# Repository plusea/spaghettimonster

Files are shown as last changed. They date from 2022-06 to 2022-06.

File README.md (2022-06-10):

# spaghettimonster

The spaghettimonster is a tool we developed for playing with wearable technology first, before making it yourself. It is basically a breakout board for an ESP32 Dev Module with six audio sockets connected to pins that have an Analog to Digital Converter (ADC). This allows one to then use audio cables to make electrical connections between the i/o pins of the ESP and textile/wearable sensors mounted around the body or in/on puppets or objects. Spaghettimonster babies are little breakout boards for audio sockets so that one can make connections with conductive thread from the socket to the textile sensor.

### CODE
* [Clock Divider's Spaghetti Monster Firmware](https://github.com/clockdiv/Spaghettimonster)

### LINKS
* [spaghettimonster intro](https://www.kobakant.at/DIY/?p=9137)
* [photos](https://www.flickr.com/photos/plusea/albums/72157719958295195)
* workshops that tested the spaghettimonster v1:
** [sensitive puppetes](https://www.flickr.com/photos/plusea/albums/72157713930789442)
** [communicating bodies]()



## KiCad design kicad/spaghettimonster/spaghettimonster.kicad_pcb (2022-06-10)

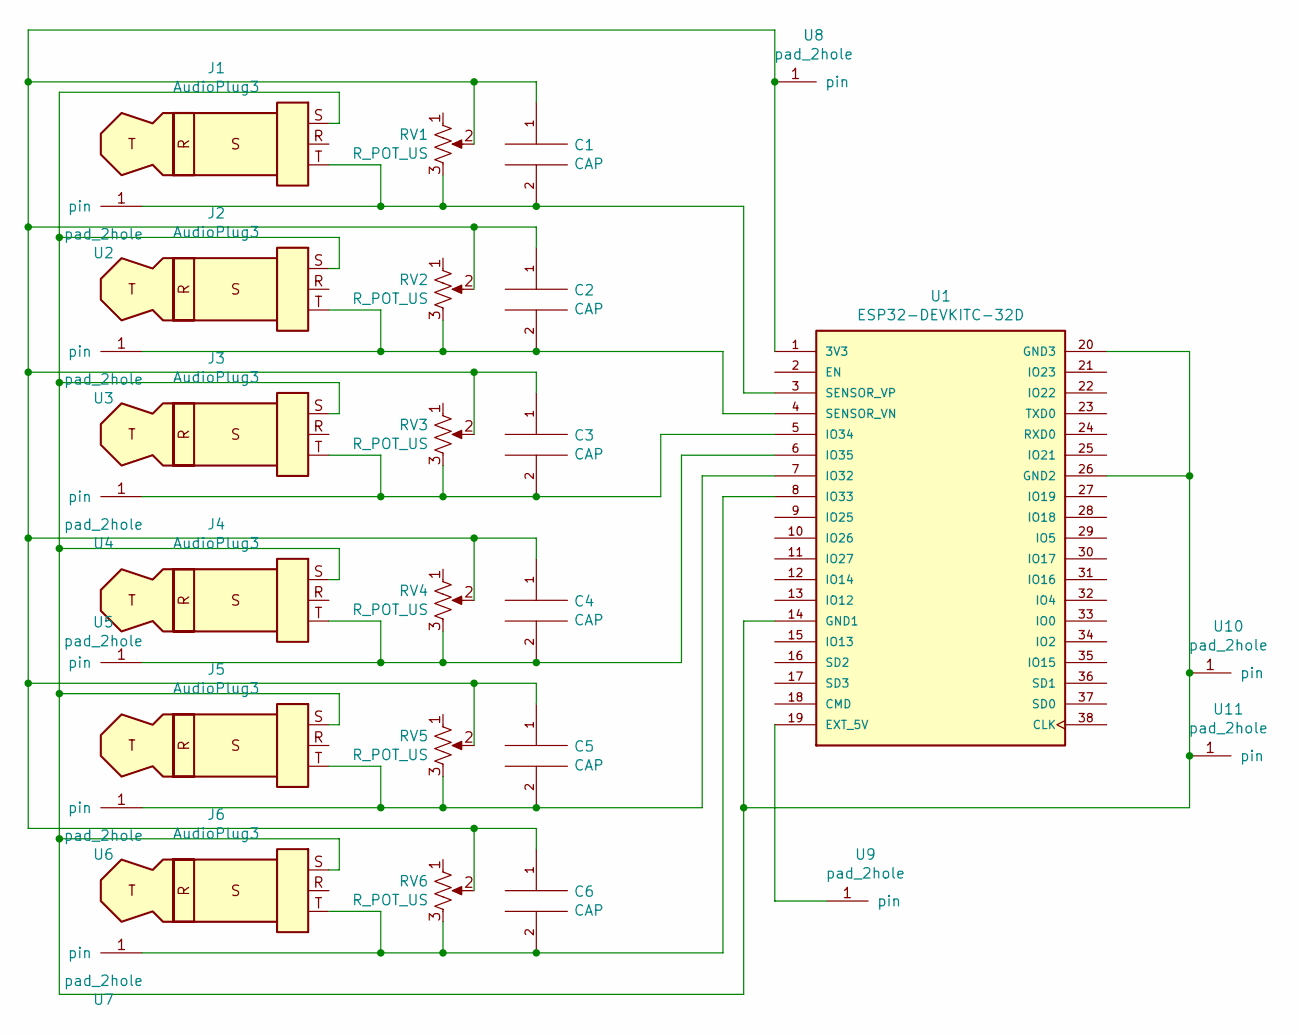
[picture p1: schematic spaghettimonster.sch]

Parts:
C1, C2, C3, C4, C5, C6: CAP; CP_Radial_D4.0mm_P2.00mm
J1, J2, J3, J4, J5, J6: AudioPlug3; Jack_3.5mm_Lumberg_1503_07_Horizontal
RV1, RV2, RV3, RV4, RV5, RV6: R_POT_US; Potentiometer_Trimmer_Piher_PT-6v_Horizontal
U1: ESP32-DEVKITC-32D; MODULE_ESP32-DEVKITC-32D; PARTREV 4
U2, U3, U4, U5, U6, U7, U8, U9, U10, U11: pad_2hole; pad_clip-edge-3mm

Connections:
unnamed: C1.1, C2.1, C3.1, C4.1, C5.1, C6.1, RV1.2, RV2.2, RV3.2, RV4.2, RV5.2, RV6.2, U1.1 (3V3), U8.1
unnamed: C1.2, J1.T, RV1.3, U1.3 (SENSOR_VP), U2.1
unnamed: C2.2, J2.T, RV2.3, U1.4 (SENSOR_VN), U3.1
unnamed: C3.2, J3.T, RV3.3, U1.5 (IO34), U4.1
unnamed: C4.2, J4.T, RV4.3, U1.6 (IO35), U5.1
unnamed: C5.2, J5.T, RV5.3, U1.7 (IO32), U6.1
unnamed: C6.2, J6.T, RV6.3, U1.8 (IO33), U7.1
unnamed: J1.S, J2.S, J3.S, J4.S, J5.S, J6.S, U1.14 (GND1), U1.20 (GND3), U1.26 (GND2), U10.1, U11.1
unnamed: U1.19 (EXT_5V), U9.1

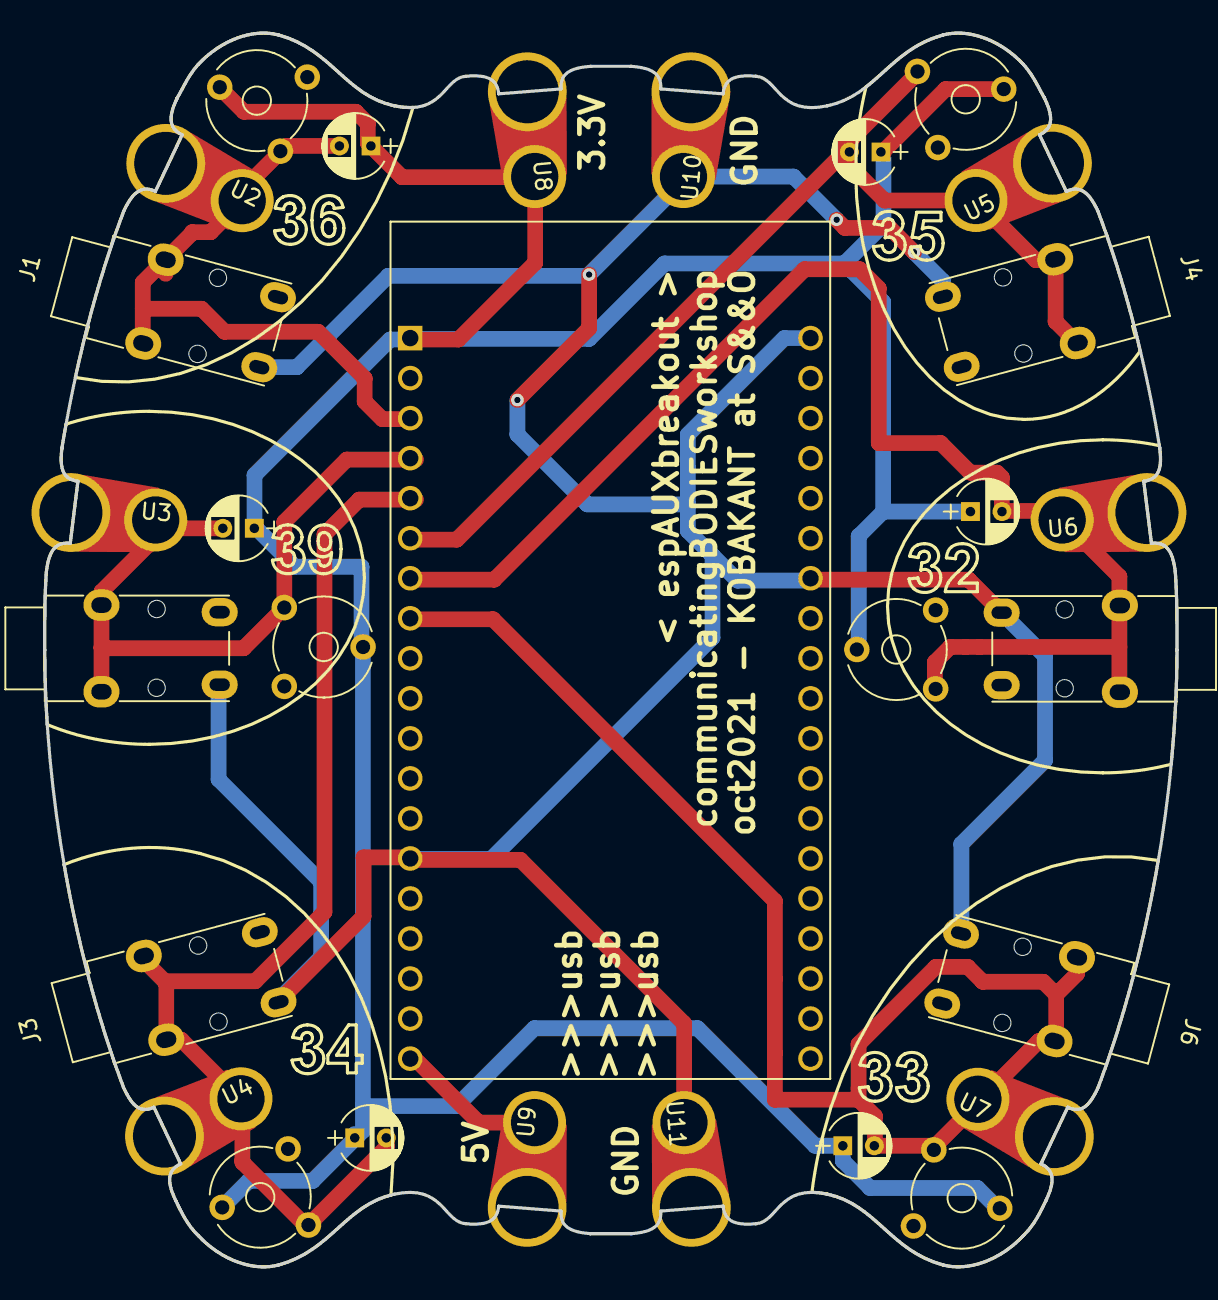
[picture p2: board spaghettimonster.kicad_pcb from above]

Board: 2 copper layers, 71.8 x 78.3 mm, 29 parts (0 on the bottom side), 9 nets.

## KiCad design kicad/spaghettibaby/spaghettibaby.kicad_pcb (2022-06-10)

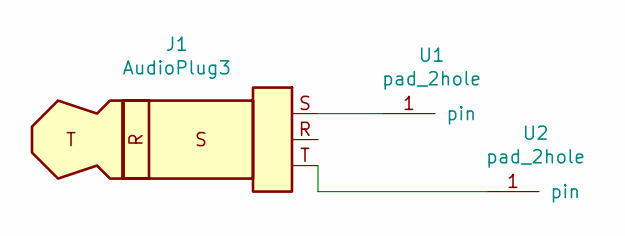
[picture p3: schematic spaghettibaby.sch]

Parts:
J1: AudioPlug3; Jack_3.5mm_Lumberg_1503_07_Horizontal
U1, U2: pad_2hole; pad_sew-edge-3x3.5mm

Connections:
unnamed: J1.S, U1.1
unnamed: J1.T, U2.1

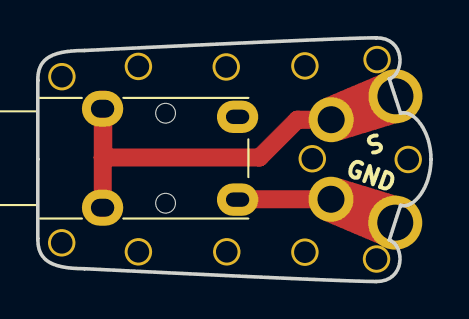
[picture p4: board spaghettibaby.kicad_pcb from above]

Board: 2 copper layers, 21.8 x 13.5 mm, 3 parts (0 on the bottom side), 2 nets.
